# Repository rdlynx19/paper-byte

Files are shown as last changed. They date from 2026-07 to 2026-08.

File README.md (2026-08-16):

# Paper Byte

Paper Byte is ESP32-S3 based e-reader,
This repository contains the PCB design files, the CAD files for the case, and the firmware to read and parse EPUB files. 

For a more detailed guide, visit my blog post - [PaperByte](https://pushkardave.com/paper-byte)

## Overview

Paper Byte parses EPUB files straight off an SD card and renders them on an e-ink screen, with three-button navigation (prev / next / select) driving a small state machine: Library, Reader, Menu, Settings, Table of Contents, and a Wi-Fi file transfer mode.

- Unzips and parses EPUBs (XHTML + metadata) from an SD card
- Reflowable text layout: word-wrap, adjustable font size, margins
- Cover art extraction and a library grid with cached thumbnails
- Table of contents / chapter jump
- Persistent reading position per book, survives power loss
- Battery percentage from a MAX17048 fuel gauge
- Sleeps to the book's cover at zero power and wakes straight back into the reader
- Wireless library management: the device hosts its own Wi-Fi access point and a small HTTP page to upload/delete EPUBs

## Hardware

| Component | Role |
|---|---|
| Adafruit ESP32-S3 Feather | Parses EPUBs, drives the display, runs the whole app |
| Waveshare 5" E-Paper Display + driver HAT | Renders pages over SPI |
| Adafruit SD Card module | EPUB storage, hot-swappable (card-detect pin) |
| MAX17048 fuel gauge (on the Feather) | Battery % over I2C |
| 3 tactile switches | Prev / Next / Select |
| 1S LiPo battery | Power, charged over the Feather's USB-C |

A custom through-hole PCB (`pcb/`) ties the Feather, SD module, and e-paper HAT together on SPI buses. The 3D-printed enclosure is in `cad/`.

## Software Architecture

```
EPUB (zip) -> unzip/parse chapter -> word-wrap into pages sized to the display -> render to e-paper
```

- Each chapter is parsed and laid out once, then cached in RAM — flipping pages just re-renders from the cache; only crossing into a new chapter costs a re-parse.
- Reading position, settings, and cover art are all cached to the SD card.

### Code layout (`code/src/`)

- `epub/` — ZIP extraction (`miniz`), XHTML parsing (`tinyxml2` + a small "rubbish" HTML parser), EPUB metadata
- `model/` — page/block layout model that turns parsed HTML into fixed-size pages
- `display/` — e-paper driver (`EPD_5in0`), drawing primitives (`GUI_Paint`), bitmap fonts, cover art rendering
- `storage/` — SD-backed reading position and settings persistence
- `power/` — MAX17048 battery fuel gauge wrapper
- `network/` — `FileServer`, the AP-mode Wi-Fi file manager

## Wireless File Manager

From the Library menu, entering File Transfer mode starts a Wi-Fi access point (SSID/password in `code/src/config.h`) and a small web page for uploading/deleting EPUBs. Idle-timeout sleep is suspended while the mode is active; exiting tears down Wi-Fi and re-scans the library.

## Future Work

- Partial e-ink refresh for page turns (currently a full refresh every page)
- Bookmarks
- A dedicated low-battery/charging screen

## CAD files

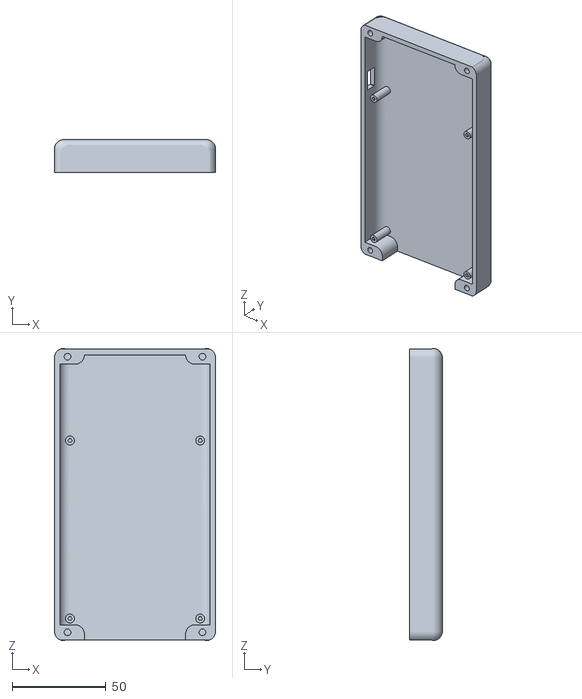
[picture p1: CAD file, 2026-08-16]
cad/Casev5-Back Cover.stl
86.0 x 17.5 x 155.8

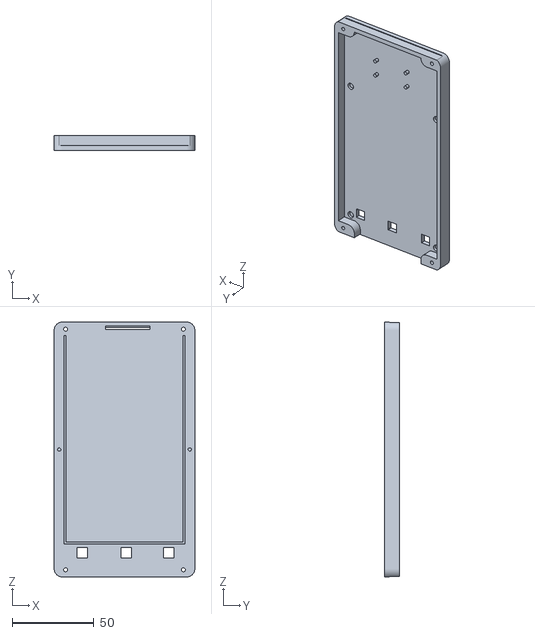
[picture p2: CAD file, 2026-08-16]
cad/Casev5-DisplayPlate.stl
86.0 x 9.25 x 155.9

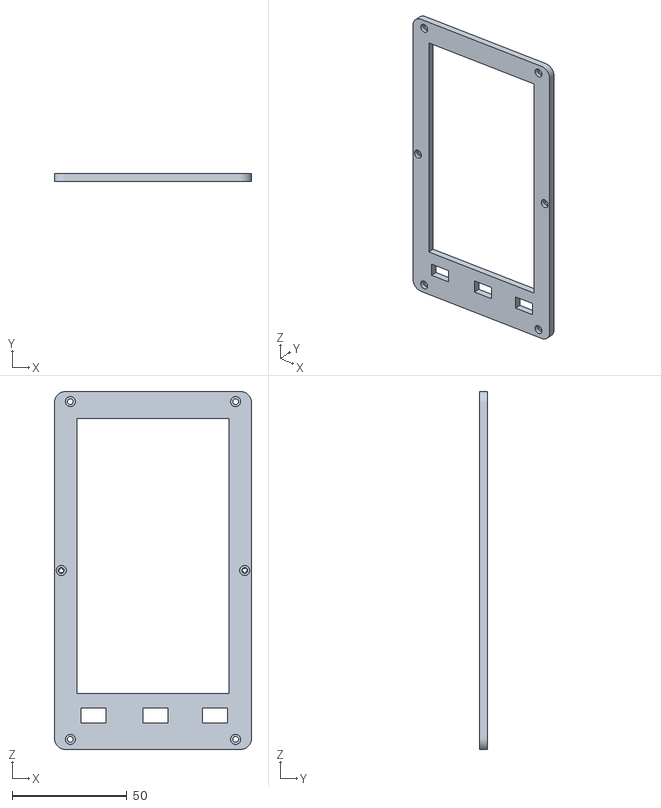
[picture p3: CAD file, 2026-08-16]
cad/Casev5-FrontCover.stl
86.0 x 3.50 x 155.9

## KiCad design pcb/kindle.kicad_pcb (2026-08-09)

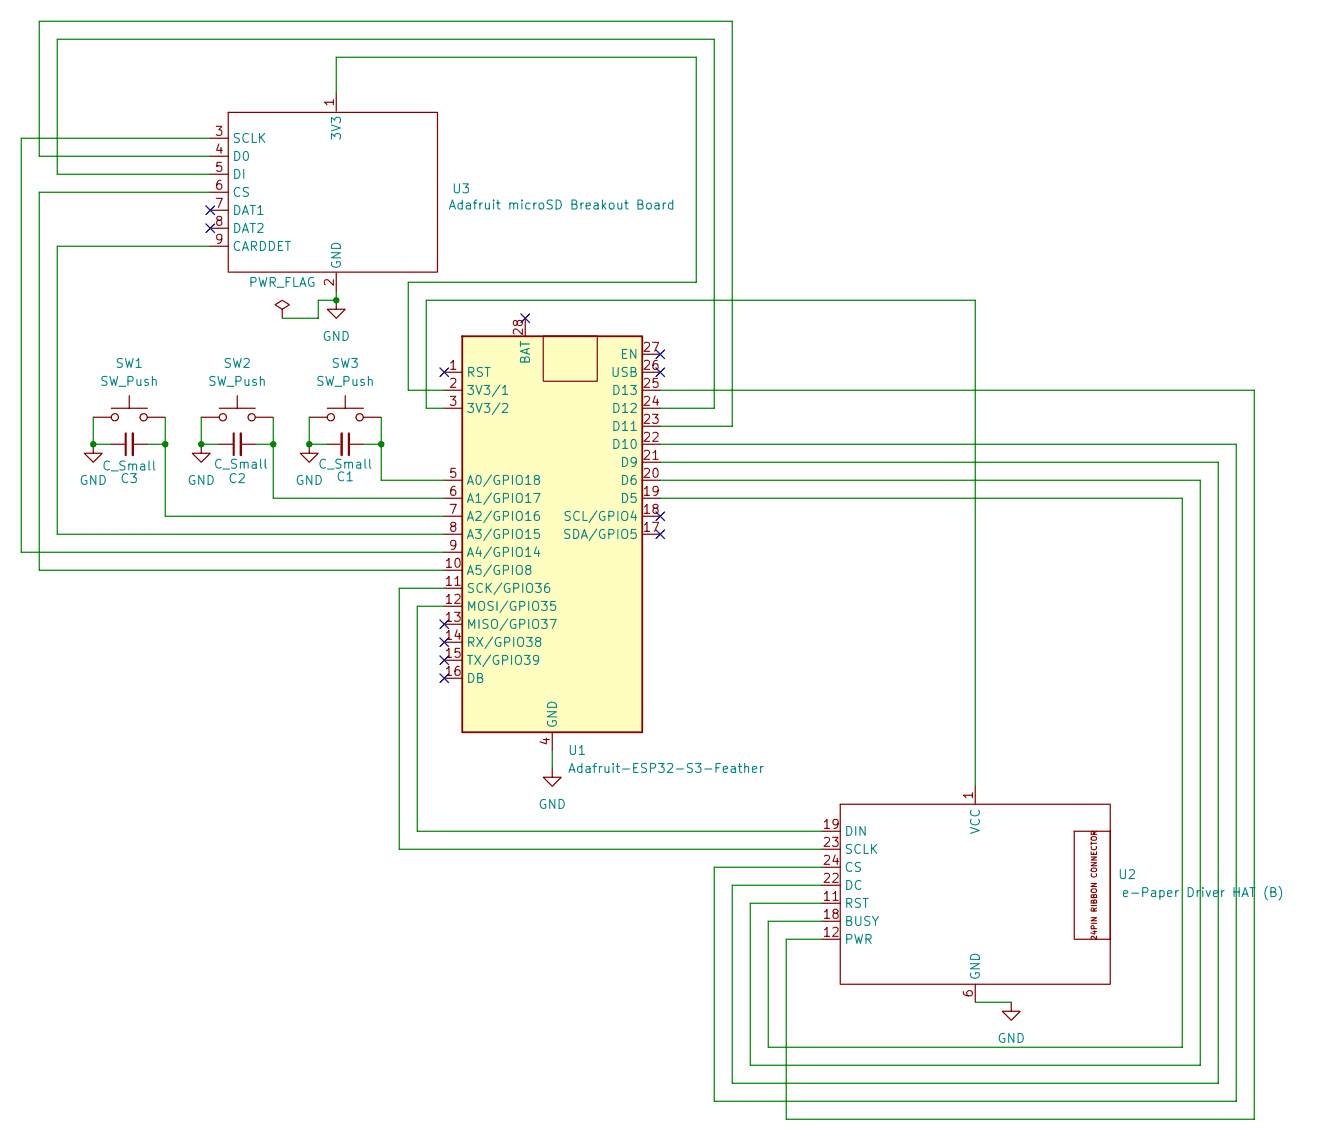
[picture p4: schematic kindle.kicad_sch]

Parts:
C1, C2, C3: C_Small; C_Disc_D3.0mm_W1.6mm_P2.50mm
SW1, SW2, SW3: SW_Push; SW_PUSH_6mm_H5mm
U1: Adafruit-ESP32-S3-Feather; Adafruit_ESP32_S3_Feather_WithMountingHoles
U2: e-Paper Driver HAT (B); MODULE_RASPBERRY_PI_ZERO_2_W
U3: Adafruit microSD Breakout Board; MODULE_MICROSD_SPI_OR_SDIO_CARD

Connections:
GND: C1.2, C2.1, C3.1, SW1.1, SW2.1, SW3.1, U1.4 (GND), U2.6 (GND), U3.2 (GND)
unnamed: U1.2 (3V3/1), U3.1 (3V3)
unnamed: U1.3 (3V3/2), U2.1 (VCC)
unnamed: C1.1, SW3.2, U1.5 (A0/GPIO18)
unnamed: C2.2, SW2.2, U1.6 (A1/GPIO17)
unnamed: C3.2, SW1.2, U1.7 (A2/GPIO16)
unnamed: U1.8 (A3/GPIO15), U3.9 (CARDDET)
unnamed: U1.9 (A4/GPIO14), U3.3 (SCLK)
unnamed: U1.10 (A5/GPIO8), U3.6 (CS)
unnamed: U1.19 (D5), U2.18 (BUSY)
unnamed: U1.20 (D6), U2.11 (RST)
unnamed: U1.21 (D9), U2.22 (DC)
unnamed: U1.22 (D10), U2.24 (CS)
unnamed: U1.23 (D11), U3.4 (D0)
unnamed: U1.24 (D12), U3.5 (DI)
unnamed: U1.25 (D13), U2.12 (PWR)
unnamed: U1.12 (MOSI/GPIO35), U2.19 (DIN)
unnamed: U1.11 (SCK/GPIO36), U2.23 (SCLK)

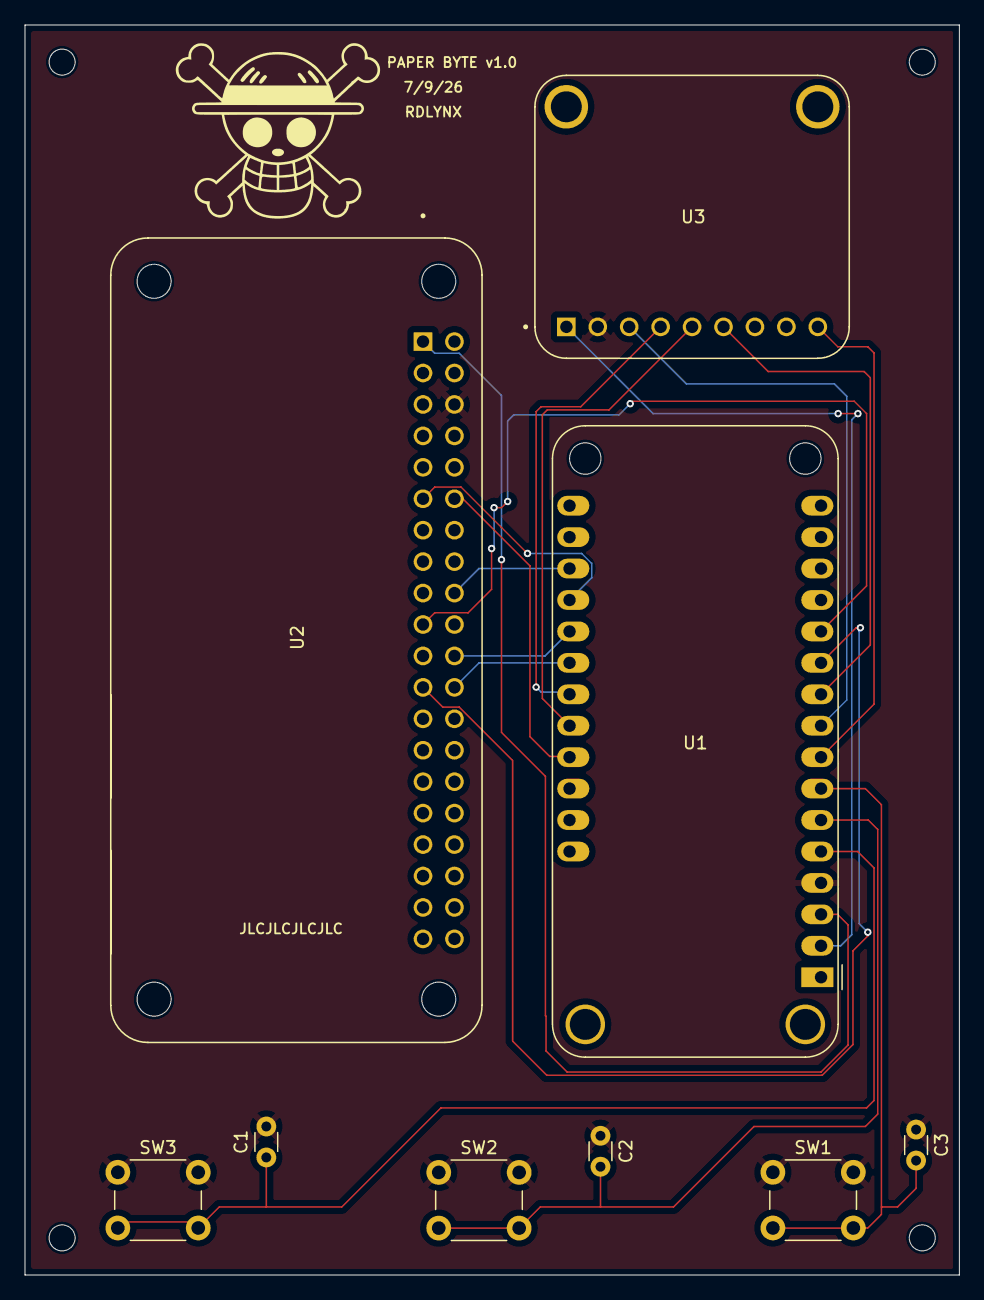
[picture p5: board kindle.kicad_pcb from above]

Board: 2 copper layers, 75.5 x 101.0 mm, 9 parts (0 on the bottom side), 18 nets.

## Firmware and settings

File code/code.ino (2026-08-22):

#include <SPI.h>
#include <SD.h>
#include <esp_sleep.h>
#include <esp_system.h>
#include <driver/rtc_io.h>
#include "src/config.h"
#include "src/model/Types.h"
#include "src/display/EPD_5in0.h"
#include "src/display/GUI_Paint.h"
#include "src/display/fonts.h"
#include "src/display/DisplayManager.h"
#include "src/display/WaveshareRenderer.h"
#include "src/epub/Epub.h"
#include "src/epub/RubbishHtmlParser.h"
#include "src/storage/PositionStore.h"
#include "src/model/State.h"
#include "src/display/CoverArt.h"
#include "src/power/Battery.h"
#include "src/storage/SettingsStore.h"
#include "src/network/FileServer.h"

size_t getArduinoLoopTaskStackSize() { return 32768; }

// =============================================================================
// Globals — only POD / trivial-constructor types live here.
// Epub*, RubbishHtmlParser*, WaveshareRenderer* are heap-allocated in setup().
// =============================================================================

DisplayManager    display;           // trivial constructor — safe as global
Battery           g_battery;          // trivial constructor — safe as global
UBYTE            *framebuf  = nullptr;
WaveshareRenderer *g_rend   = nullptr;
Epub              *g_epub   = nullptr;
RubbishHtmlParser *g_parser = nullptr;

EpubListState g_state;               // POD — zero-initialised in BSS

int g_spine_index   = 0;
int g_page_index    = 0;
int g_page_count    = 0;
int g_sel_epub      = 0;            // selected row in library screen
int g_menu_sel      = 0;            // selected row in menu
int g_settings_sel  = 0;            // selected row in settings screen
int g_toc_sel       = 0;            // selected row in table-of-contents screen
int g_library_menu_sel = 0;         // selected row in library menu

ReaderSettings g_settings;          // populated from SD in setup()/fast_resume()

AppState g_app_state = ST_LIBRARY;

unsigned long g_last_activity = 0;

// =============================================================================
// Deep-sleep state — survives power-off, lives in RTC slow memory
// =============================================================================

struct RtcSleepState {
    uint32_t magic;
    int32_t  app_state;
    int32_t  sel_epub;
    int32_t  spine_index;
    int32_t  page_index;
    int32_t  menu_sel;
};
RTC_DATA_ATTR static RtcSleepState rtc_sleep;
static const uint32_t SLEEP_MAGIC = 0x4B5A5376; // 'KZSv'

// =============================================================================
// Buttons  (active-low, internal pull-up)
// =============================================================================

// Btn and AppState enums are in Types.h (included above).

static void init_buttons() {
    pinMode(BTN_PREV,   INPUT_PULLUP);
    pinMode(BTN_NEXT,   INPUT_PULLUP);
    pinMode(BTN_SELECT, INPUT_PULLUP);
}

static const unsigned long LONG_PRESS_MS = 600;

// Post-fire cooldown per button. Contact bounce itself is filtered in
// hardware (0.1uF caps from each active pin to ground), so this only needs
// to guard against a single mechanical/electrical glitch double-firing —
// it does NOT need to be long enough to also serve as a debounce window.
// Keeping it short matters: PREV/NEXT are the rapid-repeat page-turn
// buttons, and a real fast tap-tap can be well under 200ms apart.
static const unsigned long BUTTON_COOLDOWN_MS = 50;

// SELECT distinguishes a short tap (BTN_OK) from a held press (BTN_OK_LONG —
// used to reach the Library menu). This means BTN_OK now fires on release
// rather than on press, so its action can be suppressed if the hold turns
// into a long-press instead: the first ~600ms of a long-press is
// indistinguishable from a short tap, so there's no way to know which one
// it'll be until either the threshold passes (long) or the button comes back
// up first (short). PREV/NEXT are untouched (still fire on press) since
// they're the rapid-repeat page-turn buttons and don't need this.
static Btn read_button() {
    static bool lp = false, ln = false, ls = false;
    // Each button gets its own cooldown timer — these used to share one
    // `quiet_until`, which meant a fresh press of one button could get
    // silently swallowed by another button's still-running cooldown (e.g.
    // a quick NEXT-NEXT double-tap, or NEXT immediately followed by
    // SELECT).
    static unsigned long quiet_until_left  = 0;
    static unsigned long quiet_until_right = 0;
    static unsigned long quiet_until_ok    = 0;
    static unsigned long select_press_start = 0;
    static bool select_long_fired = false;

    bool cp = digitalRead(BTN_PREV)   == LOW;
    bool cn = digitalRead(BTN_NEXT)   == LOW;
    bool cs = digitalRead(BTN_SELECT) == LOW;

    Btn b = BTN_NONE;

    if      (cp && !lp && millis() >= quiet_until_left)  { b = BTN_LEFT;  quiet_until_left  = millis() + BUTTON_COOLDOWN_MS; }
    else if (cn && !ln && millis() >= quiet_until_right) { b = BTN_RIGHT; quiet_until_right = millis() + BUTTON_COOLDOWN_MS; }

    if (cs && !ls) {
        select_press_start = millis();
        select_long_fired  = false;
    } else if (cs && select_press_start != 0 && !select_long_fired
               && millis() - select_press_start >= LONG_PRESS_MS) {
        select_long_fired = true;
        b = BTN_OK_LONG;
    } else if (!cs && ls) {
        if (!select_long_fired && millis() >= quiet_until_ok) {
            b = BTN_OK;
            quiet_until_ok = millis() + BUTTON_COOLDOWN_MS;
        }
        select_press_start = 0;
        select_long_fired  = false;
    }

    lp = cp; ln = cn; ls = cs;
    return b;
}

// =============================================================================
// SD — scan for .epub files, add new ones to g_state
// =============================================================================

static void scan_for_epubs() {
    const char *dirs[] = { EPUB_DIR, "/" };
    for (auto dir : dirs) {
        File d = SD.open(dir);
        if (!d) continue;
        while (true) {
            File f = d.openNextFile();
            if (!f) break;
            String name = f.name();
            bool   is_dir = f.isDirectory();
            f.close();
            if (is_dir) continue;
            if (!name.endsWith(".epub") && !name.endsWith(".EPUB")) continue;

            char fp[MAX_PATH_SIZE];
            if (strcmp(dir, "/") == 0)
                snprintf(fp, sizeof(fp), "/sd/%s",    name.c_str());
            else
                snprintf(fp, sizeof(fp), "/sd%s/%s",  dir, name.c_str());

            bool found = false;
            for (int i = 0; i < g_state.num_epubs && !found; i++)
                found = strncmp(g_state.epub_list[i].path, fp, MAX_PATH_SIZE) == 0;
            if (found || g_state.num_epubs >= MAX_EPUB_LIST_SIZE) continue;

            EpubListItem &it = g_state.epub_list[g_state.num_epubs++];
            memset(&it, 0, sizeof(it));
            strncpy(it.path,  fp,           MAX_PATH_SIZE  - 1);
            strncpy(it.title, name.c_str(), MAX_TITLE_SIZE - 1);
        }
        d.close();
    }
}

// =============================================================================
// Position persistence
// =============================================================================

static void save_position() {
    if (!g_epub || g_sel_epub < 0 || g_sel_epub >= g_state.num_epubs) return;
    PositionStore::set_epub_position(
        g_state,
        g_state.epub_list[g_sel_epub].path,
        g_state.epub_list[g_sel_epub].title,
        (uint16_t)g_spine_index,
        (uint16_t)g_page_index,
        (uint16_t)g_page_count);
    PositionStore::save(g_state);
}

// =============================================================================
// Deep sleep
// =============================================================================

// Draws the currently open book's cover full-bleed (or a plain
// "Sleeping..." message if it has none), so it stays visible at zero power
// while the panel sleeps — leverages e-ink's bistable hold instead of
// clearing to blank white. No title text: the cover art already carries it.
// Only called when a book is actually open (see enter_deep_sleep(), which
// clears to white otherwise). Allocated from PSRAM rather than a static
// buffer — at full-screen size (~53KB) it's not worth permanently reserving
// for a screen only drawn once, right before a multi-hour sleep.
static void render_sleep_cover() {
    g_rend->clear_screen();

    uint8_t *cover_buf = (uint8_t *)ps_malloc(COVER_SLEEP_BYTES);
    bool have_cover = cover_buf && get_cover_sleep_bitmap(g_epub, cover_buf);

    if (have_cover) {
        int x = (g_rend->get_page_width()  - COVER_SLEEP_W) / 2;
        int y = (g_rend->get_page_height() - COVER_SLEEP_H) / 2;
        g_rend->draw_bitmap_1bpp(x, y, cover_buf, COVER_SLEEP_W, COVER_SLEEP_H);
    } else {
        const char *msg = "Sleeping...";
        int text_w = (int)strlen(msg) * g_rend->get_space_width();
        g_rend->draw_text((g_rend->get_page_width() - text_w) / 2, g_rend->get_page_height() / 2, msg);
    }
    free(cover_buf);

    display.showPage(framebuf, true);
}

static void enter_deep_sleep() {
    Serial.println("Idle: entering deep sleep");
    Serial.flush();

    // Snapshot navigation state into RTC memory
    rtc_sleep.magic       = SLEEP_MAGIC;
    rtc_sleep.app_state   = (int32_t)g_app_state;
    rtc_sleep.sel_epub    = (int32_t)g_sel_epub;
    rtc_sleep.spine_index = (int32_t)g_spine_index;
    rtc_sleep.page_index  = (int32_t)g_page_index;
    rtc_sleep.menu_sel    = (int32_t)g_menu_sel;

    // Configure wakeup on any button press (active-low → wake on LOW).
    // Requires Arduino ESP32 3.x / IDF 5.x for ESP_EXT1_WAKEUP_ANY_LOW.
    uint64_t wake_mask = (1ULL << BTN_PREV) | (1ULL << BTN_NEXT) | (1ULL << BTN_SELECT);
    esp_sleep_enable_ext1_wakeup(wake_mask, ESP_EXT1_WAKEUP_ANY_LOW);

    // Enable RTC pull-ups so pins stay HIGH (not-pressed) while ESP32 is off.
    rtc_gpio_pullup_en((gpio_num_t)BTN_PREV);
    rtc_gpio_pullup_en((gpio_num_t)BTN_NEXT);
    rtc_gpio_pullup_en((gpio_num_t)BTN_SELECT);
    rtc_gpio_pulldown_dis((gpio_num_t)BTN_PREV);
    rtc_gpio_pulldown_dis((gpio_num_t)BTN_NEXT);
    rtc_gpio_pulldown_dis((gpio_num_t)BTN_SELECT);

    if (g_epub) {
        // A book is open — leave its cover on screen instead of blanking it;
        // e-ink holds the image with zero power through deep sleep.
        render_sleep_cover();
        display.sleep(false);
    } else {
        // No book open (e.g. sleeping from the library) — clear to white
        // rather than leave an arbitrary screen state burned in indefinitely.
        display.sleep(true);
    }

    esp_deep_sleep_start();
    // Never returns.
}

// Re-init after deep sleep wakeup without a full cold-boot scan.
static void fast_resume() {
    Serial.println("Waking from deep sleep...");

    // Framebuf in PSRAM
    UDOUBLE imgsize = ((EPD_W % 8 == 0) ? (EPD_W / 8) : (EPD_W / 8 + 1)) * EPD_H;
    framebuf = (UBYTE *)ps_malloc(imgsize);
    if (!framebuf) { Serial.println("FATAL: framebuf"); while (1); }

    // Re-init display registers (no panel clear — image already on screen)
    display.wake();
    Paint_NewImage(framebuf, EPD_W, EPD_H, 90, WHITE);

    // Renderer
    g_rend = new WaveshareRenderer(framebuf, EPD_H, EPD_W);
    if (!g_rend) { Serial.println("FATAL: renderer"); while (1); }

    // SD card
    static SPIClass sdSPI(HSPI);
    sdSPI.begin(SD_SCK, SD_MISO, SD_MOSI);
    if (!SD.begin(SD_CS, sdSPI)) Serial.println("WARN: SD init failed on wake");

    // Buttons
    init_buttons();

    // Battery gauge (I2C/peripheral state doesn't survive deep sleep)
    g_battery.begin();

    // Settings (regular globals don't survive deep sleep either)
    SettingsStore::load(&g_settings);
    g_rend->set_large_font(g_settings.large_font);

    // Restore navigation state from RTC memory
    g_app_state   = (AppState)rtc_sleep.app_state;
    g_sel_epub    = rtc_sleep.sel_epub;
    g_spine_index = rtc_sleep.spine_index;
    g_page_index  = rtc_sleep.page_index;
    g_menu_sel    = rtc_sleep.menu_sel;
    // Settings/TOC aren't worth round-tripping through RTC memory — fall back to Menu
    if (g_app_state == ST_SETTINGS || g_app_state == ST_TOC) g_app_state = ST_MENU;
    // Library menu / file transfer likewise fall back to the Library itself
    // (file transfer suspends idle-sleep, so this path is really only the
    // Library menu's own "Sleep" option; WiFi never survives deep sleep
    // regardless, so there's nothing meaningful to resume into anyway).
    if (g_app_state == ST_LIBRARY_MENU || g_app_state == ST_FILE_TRANSFER) g_app_state = ST_LIBRARY;

    // Load epub list from SD (needed for open_epub / render_library)
    PositionStore::load(&g_state);

    // Re-render the screen the user was on
    bool resumed = false;
    if ((g_app_state == ST_READER || g_app_state == ST_MENU)
        && g_sel_epub >= 0 && g_sel_epub < g_state.num_epubs) {
        g_epub = new Epub(g_state.epub_list[g_sel_epub].path);
        if (g_epub && g_epub->load()
            && load_spine_item(rtc_sleep.spine_index, rtc_sleep.page_index)) {
            render_current_page();
            display.showPage(framebuf, true);
            g_app_state = ST_READER;
            resumed = true;
        } else {
            delete g_epub; g_epub = nullptr;
            Serial.println("WARN: epub reload failed");
        }
    }

    if (!resumed) {
        scan_for_epubs();
        render_library();
        g_app_state = ST_LIBRARY;
    }

    // Let the wakeup button release before the main loop polls it
    delay(300);
    g_last_activity = millis();
}

// =============================================================================
// Spine / parser management
// =============================================================================

// Parse and layout spine[spine_index]. Frees the *previous* g_parser before
// building the new one (see below), so a failed load leaves g_parser null
// rather than falling back to stale content — every current caller already
// either retries with a different spine index in a loop before next
// redrawing anything, or shows its own distinct message on total failure,
// so nothing actually depends on the old content surviving a failed load.
// render_current_page() already null-checks g_parser defensively, so a
// transient null between calls can't crash — worst case is a harmless
// redundant refresh of whatever's already on screen.
static bool load_spine_item(int spine_index, int page_index) {
    if (!g_epub) return false;
    if (spine_index < 0 || spine_index >= g_epub->get_spine_items_count()) return false;

    std::string path = g_epub->get_spine_item(spine_index);
    size_t html_sz = 0;
    uint8_t *html = g_epub->get_item_contents(path, &html_sz);
    if (!html) return false;

    size_t slash = path.rfind('/');
    std::string dir = slash != std::string::npos ? path.substr(0, slash + 1) : "";

    // Free the outgoing chapter's parsed pages/blocks *before* building the
    // incoming one, not after. Keeping both alive at once (the old order)
    // doubles peak heap right at the moment a page-heavy chapter's own
    // layout() is already the single biggest heap consumer in the app —
    // confirmed as the actual crash site via a decoded panic backtrace:
    // abort() inside a fopen() call in save_position(), immediately after
    // a successful chapter-boundary load_spine_item() — i.e. exactly here.
    delete g_parser;
    g_parser = nullptr;

    RubbishHtmlParser *np = new RubbishHtmlParser((const char *)html, (int)html_sz, dir);
    free(html);

    if (!np || !np->has_text_content()) { delete np; return false; }
    np->layout(g_rend, g_epub);
    int pc = np->get_page_count();
    if (pc == 0) { delete np; return false; }

    g_parser      = np;
    g_spine_index = spine_index;
    g_page_count  = pc;
    if (page_index >= pc) page_index = pc - 1;
    if (page_index <  0) page_index = 0;
    g_page_index  = page_index;
    return true;
}

// =============================================================================
// Screen renderers
// =============================================================================

// Chapter number + title (left) and battery icon/percentage (right), drawn
// in the top margin band — a blank buffer zone above the content area on
// every screen — so it never displaces text or affects pagination. Safe to
// call from any screen renderer. Chapter label only shows while a book is
// open (Reader, Menu, Settings, TOC); it's naturally absent on the Library
// screen since g_epub is null there.
static void draw_top_strip() {
    const int y = -26; // within the top margin band, above y=0 content

    if (g_epub) {
        int toc_idx = g_epub->get_toc_index_for_spine_index(g_spine_index);
        int chapter_num = count_toplevel_toc_entries_upto(g_epub, toc_idx);
        char chapter[64];
        if (toc_idx >= 0 && !g_epub->get_toc_item(toc_idx).title.empty())
            snprintf(chapter, sizeof(chapter), "Chapter %d: %s", chapter_num, g_epub->get_toc_item(toc_idx).title.c_str());
        else
            snprintf(chapter, sizeof(chapter), "Chapter %d", chapter_num);

        // Truncate so a long chapter title can't run into the battery
        // indicator on the right — reserves a fixed margin for it whether
        // or not a battery gauge is actually present, simpler than
        // computing the exact reserved width conditionally.
        int max_chars = max(4, (g_rend->get_page_width() - 100) / g_rend->get_space_width());
        if ((int)strlen(chapter) > max_chars) chapter[max_chars] = '\0';
        g_rend->draw_text(0, y - 2, chapter);
    }

    if (!g_battery.available()) return;
    g_battery.update();

    const int icon_w = 32, icon_h = 16, nub_w = 3, nub_h = 8;
    const int x = g_rend->get_page_width() - icon_w - nub_w;

    char pct[8];
    snprintf(pct, sizeof(pct), "%d%%", g_battery.percent());
    int text_w = (int)strlen(pct) * g_rend->get_space_width();
    g_rend->draw_text(x - text_w - 6, y - 2, pct);

    g_rend->draw_rect(x, y, icon_w, icon_h, 1);
    g_rend->fill_rect(x + icon_w, y + (icon_h - nub_h) / 2, nub_w, nub_h, 1);

    int fill_w = (icon_w - 4) * g_battery.percent() / 100;
    if (fill_w > 0)
        g_rend->fill_rect(x + 2, y + 2, fill_w, icon_h - 4, 1);
}

// Shared selection-row renderer for the menu-style screens (Menu, Settings,
// Library menu, TOC): a full-width inverted bar for the selected row
// instead of a "> " cursor prefix — reads more clearly at a glance on
// e-ink than a leading cursor glyph, and doesn't need a font that renders
// bold clearly to convey selection.
static void draw_row(int y, const char *text, bool selected) {
    const int lh = g_rend->get_line_height();
    if (selected) {
        g_rend->fill_rect(0, y - 2, g_rend->get_page_width(), lh, 1);
        g_rend->draw_text_inverted(4, y, text);
    } else {
        g_rend->draw_text(4, y, text);
    }
}

static void render_current_page() {
    if (!g_parser || !g_rend || !g_epub) return;
    g_rend->clear_screen();
    g_parser->render_page(g_page_index, g_rend, g_epub);
    draw_top_strip();
}

static void show_msg(const char *line1, const char *line2 = nullptr) {
    g_rend->clear_screen();
    int mid = g_rend->get_page_height() / 2 - g_rend->get_line_height();
    g_rend->draw_text(0, mid, line1);
    if (line2) g_rend->draw_text(0, mid + g_rend->get_line_height(), line2);
    display.showPage(framebuf, true);
}

// Library is a carousel: a small preview of the previous/next book on
// either side of a large "featured" cover for the current selection.
// LEFT/RIGHT shift which index is featured — circular, unlike every other
// list screen in this app: past the last book wraps to the first, and vice
// versa (see handle_library()).
static const int CAROUSEL_GAP = 14; // horizontal gap between covers
static const int TITLE_GAP    = 6;  // space between a cover's bottom edge and its caption
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
void loop() {
    if (g_app_state == ST_FILE_TRANSFER) g_file_server.update();

    Btn b = read_button();
    if (b != BTN_NONE) {
        Serial.printf("Button: %d, state: %d, free heap: %u (min: %u)\n",
                      (int)b, (int)g_app_state, ESP.getFreeHeap(), ESP.getMinFreeHeap());
        g_last_activity = millis();
        switch (g_app_state) {
            case ST_LIBRARY:       handle_library(b);       break;
            case ST_READER:        handle_reader(b);        break;
            case ST_MENU:          handle_menu(b);          break;
            case ST_SETTINGS:      handle_settings(b);      break;
            case ST_TOC:           handle_toc(b);           break;
            case ST_LIBRARY_MENU:  handle_library_menu(b);  break;
            case ST_FILE_TRANSFER: handle_file_transfer(b); break;
        }
        Serial.println("Button: handler returned");
    }

    // Idle timeout — save position then deep sleep. Suspended during file
    // transfer: don't want to yank WiFi/the SD card mid-upload just because
    // the user hasn't touched a button while their phone does the work.
    if (g_app_state != ST_FILE_TRANSFER
        && millis() - g_last_activity > g_settings.sleep_timeout_ms) {
        save_position();
        enter_deep_sleep();  // never returns
    }

    yield();
    delay(20);  // ~50 Hz button polling
}

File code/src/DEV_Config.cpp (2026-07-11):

/*****************************************************************************
* | File      	:   DEV_Config.c
* | Author      :   Waveshare team
* | Function    :   Hardware underlying interface
* | Info        :
*----------------
* |	This version:   V1.0
* | Date        :   2020-02-19
* | Info        :
#
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
******************************************************************************/
#include "DEV_Config.h"
#include <SPI.h>

static SPISettings epd_spi(4000000, MSBFIRST, SPI_MODE0);

void GPIO_Config(void)
{
#if D_9PIN
    pinMode(EPD_PWR_PIN,  OUTPUT);
    digitalWrite(EPD_PWR_PIN , HIGH);
#endif

    pinMode(EPD_BUSY_PIN,  INPUT);
    pinMode(EPD_RST_PIN , OUTPUT);
    pinMode(EPD_DC_PIN  , OUTPUT);
    
    pinMode(EPD_SCK_PIN, OUTPUT);
    pinMode(EPD_MOSI_PIN, OUTPUT);
    pinMode(EPD_CS_PIN , OUTPUT);

    digitalWrite(EPD_CS_PIN , HIGH);
    digitalWrite(EPD_SCK_PIN, LOW);
}

void GPIO_Mode(UWORD GPIO_Pin, UWORD Mode)
{
    if(Mode == 0) {
        pinMode(GPIO_Pin , INPUT);
	} else {
		pinMode(GPIO_Pin , OUTPUT);
	}
}
/******************************************************************************
function:	Module Initialize, the BCM2835 library and initialize the pins, SPI protocol
parameter:
Info:
******************************************************************************/
UBYTE DEV_Module_Init(void)
{
	GPIO_Config();
	Serial.begin(115200);
	SPI.begin(EPD_SCK_PIN, -1, EPD_MOSI_PIN); // SCK, MISO (none), MOSI
	return 0;
}

/******************************************************************************
function:
			SPI read and write
******************************************************************************/
void DEV_SPI_WriteByte(UBYTE data)
{
    SPI.beginTransaction(epd_spi);
    digitalWrite(EPD_CS_PIN, LOW);
    SPI.transfer(data);
    digitalWrite(EPD_CS_PIN, HIGH);
    SPI.endTransaction();
}

UBYTE DEV_SPI_ReadByte()
{
    return 0xFF; // EPD is write-only, read not used
}

void DEV_SPI_Write_nByte(UBYTE *pData, UDOUBLE len)
{
    SPI.beginTransaction(epd_spi);
    digitalWrite(EPD_CS_PIN, LOW);
    SPI.transferBytes(pData, nullptr, len);
    digitalWrite(EPD_CS_PIN, HIGH);
    SPI.endTransaction();
}


void DEV_Module_Exit(void)
{
#if D_9PIN
    digitalWrite(EPD_PWR_PIN , LOW);
#endif
    digitalWrite(EPD_RST_PIN , LOW);
}

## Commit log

2026-07-11 adding first draft of arduino sketch, needs to be cleaned and organized
2026-07-11 adding current TODOs
2026-07-11 corrected rendering for special characters
    [GUI_Paint.cpp]
2026-07-11 fixed rendering of title and covers on main page
    [Epub.cpp, code.ino]
2026-07-11 added battery support, and battery charge indicator
2026-07-12 battery charging indicates correct %, but no charging indicator
    [Battery.cpp, code.ino]
2026-08-09 add cad and pcb files
    [kindle.kicad_pcb, kindle.kicad_sch]
2026-08-16 add cad files
    [Casev5-Back Cover.stl, Casev5-DisplayPlate.stl, Casev5-FrontCover.stl]
2026-08-22 fixed large book crash, added new UI, added OTA update feature
    [Epub.cpp]
